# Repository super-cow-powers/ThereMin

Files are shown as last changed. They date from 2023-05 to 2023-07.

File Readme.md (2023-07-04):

# ThereMin()
Minimal Digital Theremin, based on a pair of NE555p timers and an STM32G0.

Completed Device

## Theory of Operation
The device uses a pair of 555 timers to translate hand-position to frequency, which is measured by the STM32 and then used to modify a generated sine wave.

The 555 timers operate in the usual astable mode except with the capacitor replaced with an "antenna"; this forms a capacitor between you and the metal whose value varies with the gap between you and the antenna, which then varies the frequency of the 555 output.

The STM32 measures the period of the 555's output wave, calculating the offset from the initial state (calibration is done at power-on); the offset from the calibrated value is used to calculate an amplitude coefficient and a pitch offset. The amplitude coefficient divides a full-scale sine wave which is stored in a lookup table. The pitch offset is used to increase or decrease the time between changes of output value (by adjusting a timer's reload-point), thus stretching or compacting the output wave as required - although with an apparently exponential response, which is partially corrected by the firmware.

The signal is fed into a TDA2822 amplifier in single-ended mode (SE gave better stability on veroboard) with the input amplitude controlled by a potentiometer; the amplifier feeds into either an (optional) internal speaker or headphone jack depending on a SPDT switch.

## Hardware
The hardware is designed in KiCad. If you want to build your own, you're free to use the files so long as you don't try and blame me for anything which goes wrong as a result; it'd be nice to keep my name on the board, too.

The devices are fairly cheap - about £12-15 for the basic device with no LEDs or pitch-adjust potentiometer (which haven't been written in) - I used JLC for the boards and sourced most of the parts from DigiKey.

The cases are drilled by hand, using a 13mm bit for the rear cables, a 6.5mm and 7.5mm bit for the front switch and pot, and a 6mm bit for the (four) holes on the top. There's no drilling template, just use a centre-punch in the right place for the hole's purpose and drill. 

### "Antennae"
The Antennae (capacitor plates, really) are not too critical. Mine are made from thin brass rod which will fit into the jacks; any conductor which fits the jacks will work - make it into a loop which looks like a theremin antenna aught, with one "leg" slightly shorter than the other for the non-connected end. The bigger the antenna the more sensitive the response generally speaking, although I've found that there's not much to gain with this device from a huge antenna.

## Firmware
The firmware uses device files from ST Micro and ARM CMSIS, the rest can be blamed on me. The ST HAL is not being used, because it looked like a good idea to not use it when I started...

The software is fairly simple although does make heavy use of the DMA engine and Timers - these are described in the chip reference manual and, briefly, in comments.

### Building
The firmware builds with Make and Arm GCC (I suspect ARMCC6 would work, too, but I'm not going to try it) and should build on most *nix systems - it might work on Windows under WSL or mingw, but you're on your own with that one. For anyone who doesn't want to build the firmware, the latest binary is just in the build directory.

The firmware can be flashed with your favourite flashing tool; a script for an ST-Link V2 with OpenOCD is provided, but I recommend just using STMCubeProg if you're either inexperienced or running Windows. 

-----

This was initially designed as a lab kit for the [York Engineering Society](https://github.com/EngYork).

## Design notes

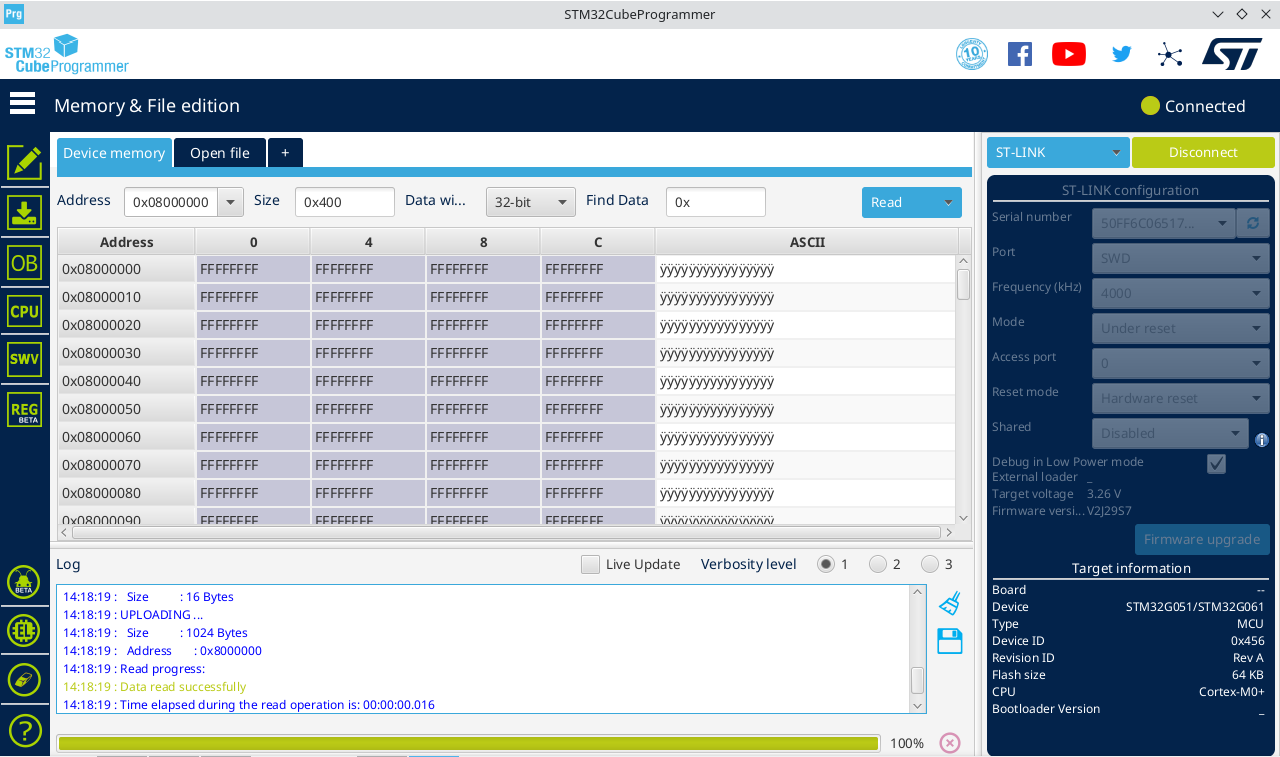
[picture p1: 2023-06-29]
cube prog.png

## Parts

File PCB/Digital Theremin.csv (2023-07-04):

Source: | /home/david/ThereMin/PCB/Digital Theremin.kicad_sch
Date: | Tue 04 Jul 2023 15:31:06 BST
Tool: | Eeschema 6.0.11-3.fc37
Generator: | /usr/share/kicad/plugins/bom_csv_grouped_by_value.py
Component Count: | 59
Individual Components:
Item | Qty | Reference(s) | Value | LibPart | Footprint | Datasheet | PN
 |  | ANT1 | Antenna | Device:Antenna | MountingHole:MountingHole_3.2mm_M3_Pad_Via | ~ | PRT-09739
 |  | ANT2 | Antenna | Device:Antenna | MountingHole:MountingHole_3.2mm_M3_Pad_Via | ~ | PRT-09739
 |  | C1 | .1u | Device:C | Capacitor_THT:C_Rect_L4.0mm_W2.5mm_P2.50mm | ~
 |  | C2 | .1u | Device:C | Capacitor_THT:C_Rect_L4.0mm_W2.5mm_P2.50mm | ~
 |  | C3 | .1u | Device:C | Capacitor_THT:C_Rect_L4.0mm_W2.5mm_P2.50mm | ~
 |  | C4 | 1u | Device:C | Capacitor_THT:C_Rect_L4.0mm_W2.5mm_P2.50mm | ~
 |  | C5 | .1u | Device:C | Capacitor_THT:C_Rect_L4.0mm_W2.5mm_P2.50mm | ~
 |  | C6 | 100u | Device:C_Polarized | Capacitor_THT:CP_Radial_D5.0mm_P2.50mm | ~ | ESK107M016AC3AA
 |  | C7 | 100u | Device:C_Polarized | Capacitor_THT:CP_Radial_D5.0mm_P2.50mm | ~ | ESK107M016AC3AA
 |  | C8 | 470u | Device:C_Polarized | Capacitor_THT:CP_Radial_D5.0mm_P2.50mm | ~ | 860010273011
 |  | C9 | .1u | Device:C | Capacitor_THT:C_Rect_L4.0mm_W2.5mm_P2.50mm | ~
 |  | C10 | .1u | Device:C | Capacitor_THT:C_Rect_L4.0mm_W2.5mm_P2.50mm | ~
 |  | C12 | .1u | Device:C | Capacitor_THT:C_Rect_L4.0mm_W2.5mm_P2.50mm | ~
 |  | C13 | .1u | Device:C | Capacitor_THT:C_Rect_L4.0mm_W2.5mm_P2.50mm | ~
 |  | C14 | .1u | Device:C | Capacitor_THT:C_Rect_L4.0mm_W2.5mm_P2.50mm | ~
 |  | C15 | .1u | Device:C | Capacitor_THT:C_Rect_L4.0mm_W2.5mm_P2.50mm | ~
 |  | C16 | DNF | Device:C | Capacitor_THT:C_Rect_L4.0mm_W2.5mm_P2.50mm | ~
 |  | D1 | DNF | Device:LED | LED_THT:LED_D5.0mm | ~
 |  | D2 | DNF | Device:LED | LED_THT:LED_D5.0mm | ~
 |  | D3 | DNF | Device:LED | LED_THT:LED_D5.0mm | ~
 |  | D4 | D_Zener 12V | Device:D_Zener | Diode_THT:D_DO-41_SOD81_P10.16mm_Horizontal | ~
 |  | D5 | D | Device:D_Schottky | Diode_THT:D_DO-41_SOD81_P10.16mm_Horizontal | ~
 |  | D6 | D | Device:D_Schottky | Diode_THT:D_DO-41_SOD81_P10.16mm_Horizontal | ~
 |  | H1 | MountingHole_Pad | Mechanical:MountingHole_Pad | MountingHole:MountingHole_3.7mm_Pad | ~
 |  | H2 | MountingHole_Pad | Mechanical:MountingHole_Pad | MountingHole:MountingHole_3.7mm_Pad | ~
 |  | J1 | Conn_01x02_Female | Connector:Conn_01x02_Female | Connector_PinHeader_2.54mm:PinHeader_1x02_P2.54mm_Vertical | ~
 |  | J2 | AudioJack3_Dual_Switch | Connector:AudioJack3_Dual_Switch | Connector_Audio:Jack_3.5mm_CUI_SJ1-3525N_Horizontal | ~ | SJ1-3525NG-PI
 |  | J3 | USB_B_Micro | Connector:USB_B_Micro | Connector_USB:USB_Micro-B_Amphenol_10104110_Horizontal | ~
 |  | J4 | Conn_01x03_Female | Connector:Conn_01x03_Female | Connector_PinHeader_2.54mm:PinHeader_1x03_P2.54mm_Vertical | ~
 |  | JP1 | Jumper_2_Open | Jumper:Jumper_2_Open | Jumper:SolderJumper-2_P1.3mm_Open_TrianglePad1.0x1.5mm | ~
 |  | JP2 | Jumper_2_Open | Jumper:Jumper_2_Open | Jumper:SolderJumper-2_P1.3mm_Open_TrianglePad1.0x1.5mm | ~
 |  | R1 | DNF | Device:R | Resistor_THT:R_Axial_DIN0207_L6.3mm_D2.5mm_P10.16mm_Horizontal | ~
 |  | R2 | DNF | Device:R | Resistor_THT:R_Axial_DIN0207_L6.3mm_D2.5mm_P10.16mm_Horizontal | ~
 |  | R3 | DNF | Device:R | Resistor_THT:R_Axial_DIN0207_L6.3mm_D2.5mm_P10.16mm_Horizontal | ~
 |  | R4 | DNF | Device:R | Resistor_THT:R_Axial_DIN0207_L6.3mm_D2.5mm_P10.16mm_Horizontal | ~
 |  | R5 | 510k | Device:R | Resistor_THT:R_Axial_DIN0207_L6.3mm_D2.5mm_P10.16mm_Horizontal | ~
 |  | R7 | 4.7 | Device:R | Resistor_THT:R_Axial_DIN0207_L6.3mm_D2.5mm_P10.16mm_Horizontal | ~
 |  | R10 | 1K | Device:R | Resistor_THT:R_Axial_DIN0207_L6.3mm_D2.5mm_P10.16mm_Horizontal | ~
 |  | R11 | 1K | Device:R | Resistor_THT:R_Axial_DIN0207_L6.3mm_D2.5mm_P10.16mm_Horizontal | ~
 |  | R12 | 1Meg | Device:R | Resistor_THT:R_Axial_DIN0207_L6.3mm_D2.5mm_P10.16mm_Horizontal | ~
 |  | R13 | 1Meg | Device:R | Resistor_THT:R_Axial_DIN0207_L6.3mm_D2.5mm_P10.16mm_Horizontal | ~
 |  | R14 | 1Meg | Device:R | Resistor_THT:R_Axial_DIN0207_L6.3mm_D2.5mm_P10.16mm_Horizontal | ~
 |  | R15 | 1Meg | Device:R | Resistor_THT:R_Axial_DIN0207_L6.3mm_D2.5mm_P10.16mm_Horizontal | ~
 |  | R16 | 10k | Device:R | Resistor_THT:R_Axial_DIN0207_L6.3mm_D2.5mm_P10.16mm_Horizontal | ~
 |  | R17 | 10k | Device:R | Resistor_THT:R_Axial_DIN0207_L6.3mm_D2.5mm_P10.16mm_Horizontal | ~
 |  | RV1 | DNF | Device:R_Potentiometer | Connector_PinHeader_2.54mm:PinHeader_1x03_P2.54mm_Vertical | ~
 |  | RV2 | 10k | Device:R_Potentiometer | Connector_PinHeader_2.54mm:PinHeader_1x03_P2.54mm_Vertical | ~
 |  | SP1 | Speaker | Device:Speaker | Connector_PinHeader_2.54mm:PinHeader_1x02_P2.54mm_Vertical | ~
 |  | SW1 | DNF | Switch:SW_Push | Button_Switch_THT:SW_PUSH_6mm | ~
 |  | SW2 | DNF | Switch:SW_Push | Button_Switch_THT:SW_PUSH_6mm | ~
 |  | SW3 | SW_SPDT | Switch:SW_SPDT | Connector_PinHeader_2.54mm:PinHeader_1x03_P2.54mm_Vertical | ~
 |  | SWD1 | Conn_ARM_JTAG_SWD_10 | Connector:Conn_ARM_JTAG_SWD_10 | Connector_PinHeader_1.27mm:PinHeader_2x05_P1.27mm_Vertical | http://infocenter.arm.com/help/topic/com.arm.doc.ddi0314h/DDI0314H_coresight_components_trm.pdf | 20021111-00010T1LF
 |  | TP1 | TestPoint | Connector:TestPoint | TestPoint:TestPoint_Loop_D2.50mm_Drill1.0mm | ~
 |  | TP2 | TestPoint | Connector:TestPoint | TestPoint:TestPoint_Loop_D2.50mm_Drill1.0mm | ~
 |  | U1 | AP2204K-3.0 | Regulator_Linear:AP2204K-3.0 | Package_TO_SOT_SMD:SOT-23-5 | https://www.diodes.com/assets/Datasheets/AP2204.pdf
 |  | U2 | TDA2822 | project_lib:TDA2822 | Package_SO:SOIC-8_3.9x4.9mm_P1.27mm
 |  | U3 | NE555P | Timer:NE555P | Package_DIP:DIP-8_W7.62mm | http://www.ti.com/lit/ds/symlink/ne555.pdf
 |  | U4 | NE555P | Timer:NE555P | Package_DIP:DIP-8_W7.62mm | http://www.ti.com/lit/ds/symlink/ne555.pdf
 |  | U5 | STM32G051K8T6 | MCU_ST_STM32G0:STM32G071KxT | Package_QFP:LQFP-32_7x7mm_P0.8mm | https://www.st.com/resource/en/datasheet/stm32g071kb.pdf
Collated Components:
Item | Qty | Reference(s) | Value | LibPart | Footprint | Datasheet | PN
1 | 2 | ANT1, ANT2 | Antenna | Device:Antenna | MountingHole:MountingHole_3.2mm_M3_Pad_Via | ~ | PRT-09739
2 | 10 | C1, C2, C3, C5, C9, C10, C12, C13, C14, C15 | .1u | Device:C | Capacitor_THT:C_Rect_L4.0mm_W2.5mm_P2.50mm | ~
3 | 1 | C4 | 1u | Device:C | Capacitor_THT:C_Rect_L4.0mm_W2.5mm_P2.50mm | ~
4 | 2 | C6, C7 | 100u | Device:C_Polarized | Capacitor_THT:CP_Radial_D5.0mm_P2.50mm | ~ | ESK107M016AC3AA
5 | 1 | C8 | 470u | Device:C_Polarized | Capacitor_THT:CP_Radial_D5.0mm_P2.50mm | ~ | 860010273011
6 | 1 | C16 | DNF | Device:C | Capacitor_THT:C_Rect_L4.0mm_W2.5mm_P2.50mm | ~
7 | 3 | D1, D2, D3 | DNF | Device:LED | LED_THT:LED_D5.0mm | ~
8 | 1 | D4 | D_Zener 12V | Device:D_Zener | Diode_THT:D_DO-41_SOD81_P10.16mm_Horizontal | ~
9 | 2 | D5, D6 | D | Device:D_Schottky | Diode_THT:D_DO-41_SOD81_P10.16mm_Horizontal | ~
10 | 2 | H1, H2 | MountingHole_Pad | Mechanical:MountingHole_Pad | MountingHole:MountingHole_3.7mm_Pad | ~
11 | 1 | J1 | Conn_01x02_Female | Connector:Conn_01x02_Female | Connector_PinHeader_2.54mm:PinHeader_1x02_P2.54mm_Vertical | ~
12 | 1 | J2 | AudioJack3_Dual_Switch | Connector:AudioJack3_Dual_Switch | Connector_Audio:Jack_3.5mm_CUI_SJ1-3525N_Horizontal | ~ | SJ1-3525NG-PI
13 | 1 | J3 | USB_B_Micro | Connector:USB_B_Micro | Connector_USB:USB_Micro-B_Amphenol_10104110_Horizontal | ~
14 | 1 | J4 | Conn_01x03_Female | Connector:Conn_01x03_Female | Connector_PinHeader_2.54mm:PinHeader_1x03_P2.54mm_Vertical | ~
15 | 2 | JP1, JP2 | Jumper_2_Open | Jumper:Jumper_2_Open | Jumper:SolderJumper-2_P1.3mm_Open_TrianglePad1.0x1.5mm | ~
16 | 4 | R1, R2, R3, R4 | DNF | Device:R | Resistor_THT:R_Axial_DIN0207_L6.3mm_D2.5mm_P10.16mm_Horizontal | ~
17 | 1 | R5 | 510k | Device:R | Resistor_THT:R_Axial_DIN0207_L6.3mm_D2.5mm_P10.16mm_Horizontal | ~
18 | 1 | R7 | 4.7 | Device:R | Resistor_THT:R_Axial_DIN0207_L6.3mm_D2.5mm_P10.16mm_Horizontal | ~
19 | 2 | R10, R11 | 1K | Device:R | Resistor_THT:R_Axial_DIN0207_L6.3mm_D2.5mm_P10.16mm_Horizontal | ~
20 | 4 | R12, R13, R14, R15 | 1Meg | Device:R | Resistor_THT:R_Axial_DIN0207_L6.3mm_D2.5mm_P10.16mm_Horizontal | ~
21 | 2 | R16, R17 | 10k | Device:R | Resistor_THT:R_Axial_DIN0207_L6.3mm_D2.5mm_P10.16mm_Horizontal | ~
22 | 1 | RV1 | DNF | Device:R_Potentiometer | Connector_PinHeader_2.54mm:PinHeader_1x03_P2.54mm_Vertical | ~
23 | 1 | RV2 | 10k | Device:R_Potentiometer | Connector_PinHeader_2.54mm:PinHeader_1x03_P2.54mm_Vertical | ~
24 | 1 | SP1 | Speaker | Device:Speaker | Connector_PinHeader_2.54mm:PinHeader_1x02_P2.54mm_Vertical | ~
25 | 2 | SW1, SW2 | DNF | Switch:SW_Push | Button_Switch_THT:SW_PUSH_6mm | ~
26 | 1 | SW3 | SW_SPDT | Switch:SW_SPDT | Connector_PinHeader_2.54mm:PinHeader_1x03_P2.54mm_Vertical | ~
27 | 1 | SWD1 | Conn_ARM_JTAG_SWD_10 | Connector:Conn_ARM_JTAG_SWD_10 | Connector_PinHeader_1.27mm:PinHeader_2x05_P1.27mm_Vertical | http://infocenter.arm.com/help/topic/com.arm.doc.ddi0314h/DDI0314H_coresight_components_trm.pdf | 20021111-00010T1LF
28 | 2 | TP1, TP2 | TestPoint | Connector:TestPoint | TestPoint:TestPoint_Loop_D2.50mm_Drill1.0mm | ~
29 | 1 | U1 | AP2204K-3.0 | Regulator_Linear:AP2204K-3.0 | Package_TO_SOT_SMD:SOT-23-5 | https://www.diodes.com/assets/Datasheets/AP2204.pdf
30 | 1 | U2 | TDA2822 | project_lib:TDA2822 | Package_SO:SOIC-8_3.9x4.9mm_P1.27mm
31 | 2 | U3, U4 | NE555P | Timer:NE555P | Package_DIP:DIP-8_W7.62mm | http://www.ti.com/lit/ds/symlink/ne555.pdf
32 | 1 | U5 | STM32G051K8T6 | MCU_ST_STM32G0:STM32G071KxT | Package_QFP:LQFP-32_7x7mm_P0.8mm | https://www.st.com/resource/en/datasheet/stm32g071kb.pdf

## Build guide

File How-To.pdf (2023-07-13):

Building Your Theremin.

## Parts

To build your Theremin, you will need the following parts:

- 10 * 0.1uF capacitors (C1, C2, C3, C5, C9, C10, C12, C13, C14, C15)
- 1 * 1uF capacitor (C4)
- 2 * 100uF capacitors (C6, C7)
- 1 * 470uF capacitor (C8)
- 2 * DO-41 size Schottky diodes (D5, D6)
- 1 * CUI SJ1-3525N 3.5mm audio jack (J2)
- 1 * Amphenol 10104110 USB port (J3)
- 1 * 510k resistor (R5)
- 1 * 4.7r resistor (R7)
- 2 * 1k resistors (R10, R11)
- 4 * 1M resistors (R12, R13, R14, R15)
- 2 * 10k resistors (R16, R17)
- 1 * 0.05” 10-pin debug header (SWD1)
- 1 * AP2204K-3.0 (pre-fitted) (U1)
- 1 * TDA2822 (pre-fitted) (U2)
- 2 * NE555P (U3, U4)
- 1 * STM32G051K8T6 (U5)
- 1 * 10k potentiometer (RV2)
- 1 * SPDT switch (SW3)
- 2 * SparkFun PRT-09739 binding posts (ANT1, ANT2)
- 1 * Hammond 1591XXSTBU, 1591XXSSBK, or 1591XXSSFLBK case.
- Antenna rods

## Surface Mount Parts

If your board is partially assembled, the only Surface Mount part is the STM32 microcontroller, U5. This should be fitted first as it can be fiddly and is not made easier by having other parts in the way.

First apply plenty of Flux to the U5 pad, then, using tweezers, grab the chip by the sides (just above the legs) and place it in position with the dot on the chip at the same corner as the line on the board (see below).

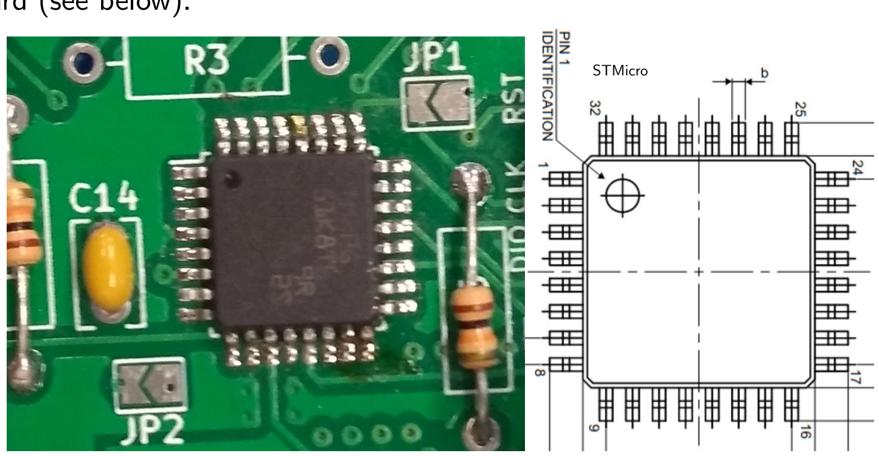
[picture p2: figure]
STMicro

Once in place, you can drag solder the chip. First solder a corner pin and then solder a pin at the opposite corner; then add solder to your iron’s tip and drag along each row of pins in turn – you may have to add more flux for each row.

For a detailed explanation, watch this video: https://youtu.be/hoLf8gvvXXU?t=363

Once you have soldered all four rows, check for solder
between any of the pins. These “bridges” can, if small,

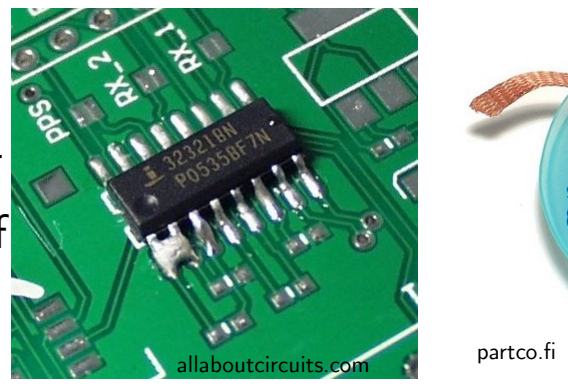
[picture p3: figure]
allaboutcircuits.com; partco.fi

be removed with flux and a clean tip; if they are larger
then apply flux, lay a short bit of solder wick on top of the bridged pins, and press the tip onto the wick
dragging along the area (make sure to remove the
wick whilst the iron is still in place!).

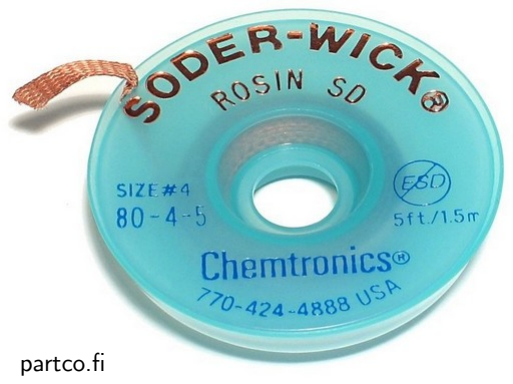
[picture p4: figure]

A hot-air gun can also work on small bridges, with the solder flowing into the pads.

The other Surface Mount parts (TDA2822, AP2204K-3.0, USB Port) can now be fitted, if they are not already. They are soldered in a similar way to the STM32, but are easier as they have a larger pin pitch.

## Through Hole Parts

The THT parts can now be attached. Start with the resistors and diodes, then attach the debug header and audio jack, then attach the two NE555 chips, then the capacitors.

An optional speaker may be connected, if available, to SP1.

### Special Instructions

The switch, potentiometer, and binding posts require special care and attention.

### Binding Posts

The binding posts should have the top plastic unscrewed and removed as well as all the nuts and washers removed (if attached); they should then be soldered in position on the top of the board using plenty of solder and with Blu Tack to keep them straight, once attached the threaded part sticking through the bottom of the board should be snipped off to allow the board to mount in the case.

### Switch and Potentiometer

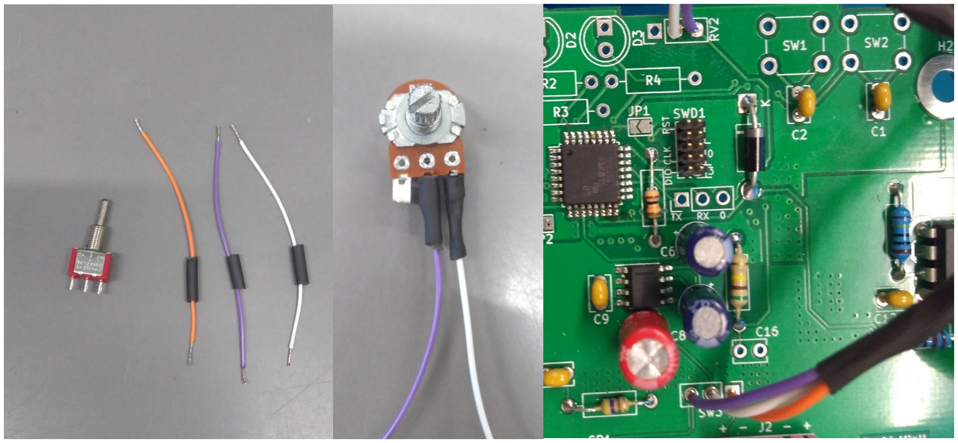
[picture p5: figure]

The switch and potentiometer attach with wires. For the switch cut three equal-length wires and for the potentiometer cut two - stripping, twisting, and adding solder to the ends of each wire.

Attach the three wires to the three switch pins and connect the wires to the board (SW3) in the same order as on the switch.

Attach the two wires to the inner and one outer pin of the potentiometer, connecting these between the two circular pads of the RV2.

## Case

The case can now be prepared. It is required to drill two holes in the front, two in the back, and four in the top.

The front needs a 6.5mm hole for the switch and a 7.5mm hole for the potentiometer.

The back needs two 13mm holes for the USB port and the audio jack.

The top needs two 6mm (or 6.5mm if you prefer) holes at each end with one hole per pair exactly above the hole in the binding post when the board is mounted in the case and with the other hole positioned to allow the second leg of each antenna to enter the case and prevent the antenna moving around.

All the holes should be marked out first using a centre-punch and engineer’s square.

## Antennae

The “antennae” can be made from any conductive rod which will fit into the binding posts and is easy to work, and should be made to a scale correct for the size of the case.

For the left side, you need a wide antenna which is roughly parallel to the desk; for the right side a long, thin, roughly vertical antenna is required. Make both of these with two legs.

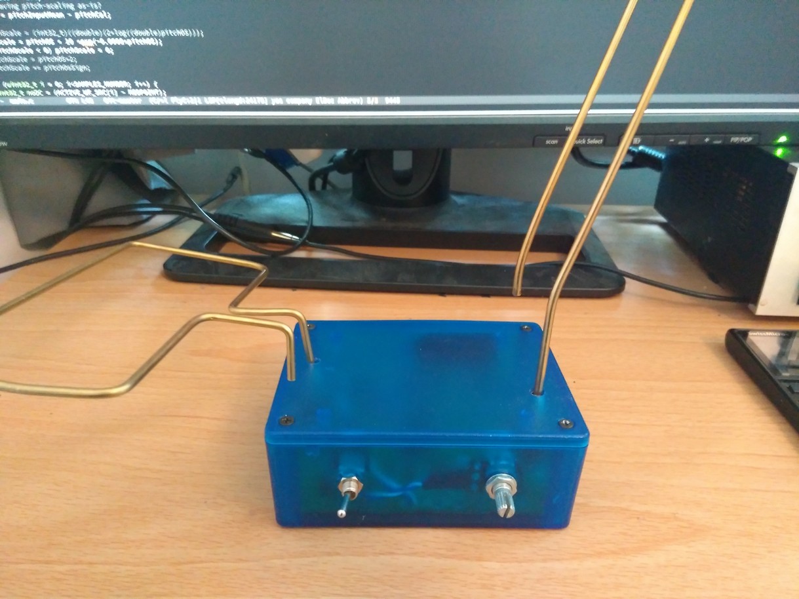
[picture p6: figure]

## Programming

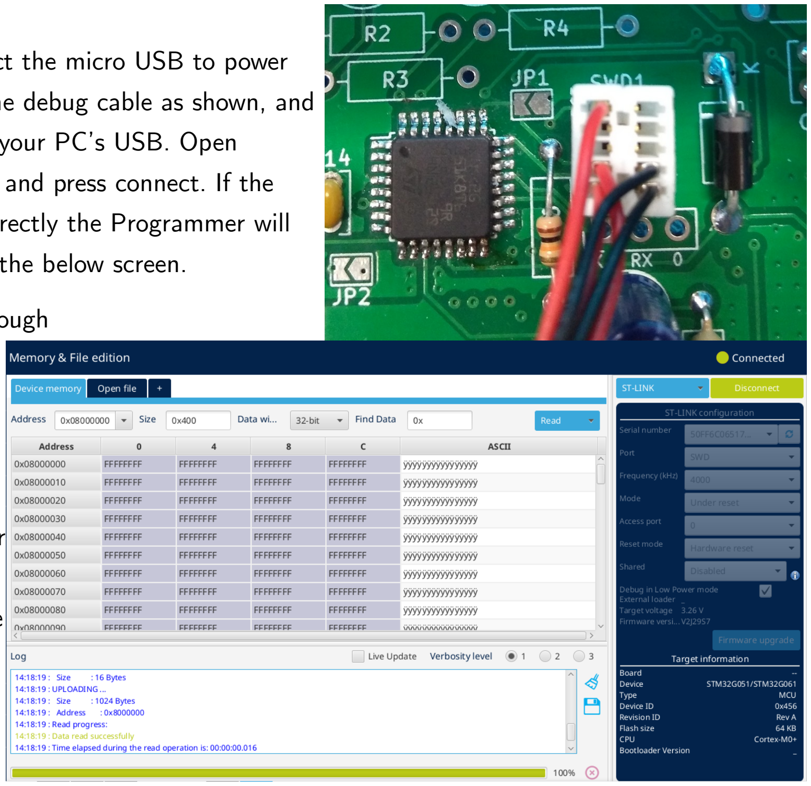
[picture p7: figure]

To test the device connect the micro USB to power the Theremin, connect the debug cable as shown, and connect the debugger to your PC’s USB. Open STM32CubeProgrammer and press connect. If the board is built roughly correctly the Programmer will connect and you will see the below screen.

Flash the programme through STM32CubeProgrammer
– Open File and write,
then disconnect.

If the board is correct, a sound will be heard either on the audio jack or
speaker depending on the
switch position; the
sound should change
when the binding posts
are touched.

If no output is seen, check your board for bad connections.

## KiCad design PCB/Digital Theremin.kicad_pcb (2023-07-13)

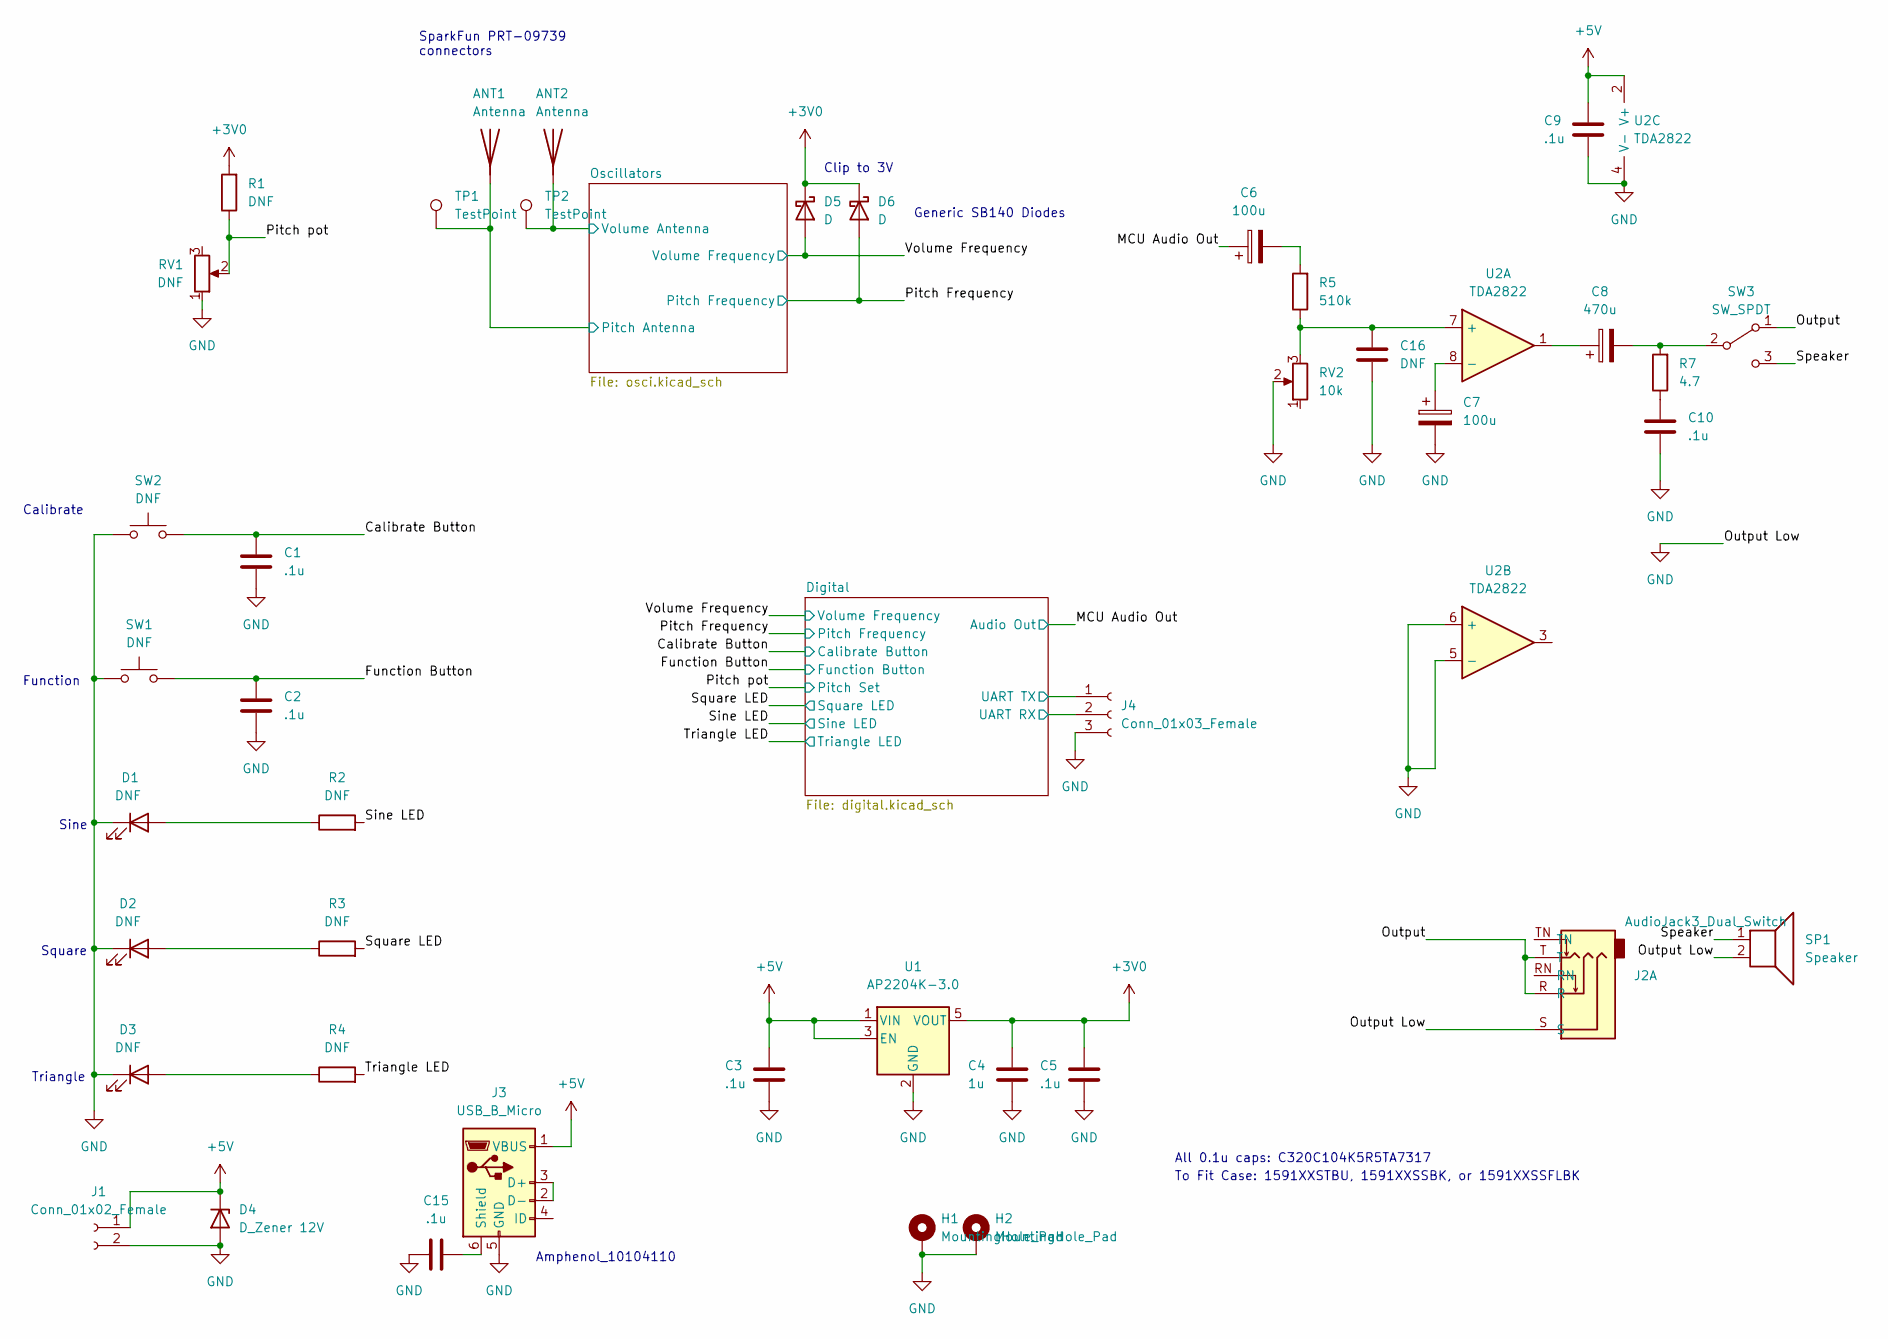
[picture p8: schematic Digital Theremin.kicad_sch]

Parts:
ANT1, ANT2: Antenna; MountingHole_3.2mm_M3_Pad_Via
C1, C2, C3, C5, C9, C10, C15: .1u; C_Rect_L4.0mm_W2.5mm_P2.50mm
C4: 1u; C_Rect_L4.0mm_W2.5mm_P2.50mm
C6, C7: 100u; CP_Radial_D5.0mm_P2.50mm
C8: 470u; CP_Radial_D5.0mm_P2.50mm
C16: DNF; C_Rect_L4.0mm_W2.5mm_P2.50mm
D1, D2, D3: DNF; LED_D5.0mm
D4: D_Zener 12V; D_DO-41_SOD81_P10.16mm_Horizontal
D5, D6: D; D_DO-41_SOD81_P10.16mm_Horizontal
H1, H2: MountingHole_Pad; MountingHole_3.7mm_Pad
J1: Conn_01x02_Female; PinHeader_1x02_P2.54mm_Vertical
J2: AudioJack3_Dual_Switch; Jack_3.5mm_CUI_SJ1-3525N_Horizontal
J3: USB_B_Micro; USB_Micro-B_Amphenol_10104110_Horizontal
J4: Conn_01x03_Female; PinHeader_1x03_P2.54mm_Vertical
R1, R2, R3, R4: DNF; R_Axial_DIN0207_L6.3mm_D2.5mm_P10.16mm_Horizontal
R5: 510k; R_Axial_DIN0207_L6.3mm_D2.5mm_P10.16mm_Horizontal
R7: 4.7; R_Axial_DIN0207_L6.3mm_D2.5mm_P10.16mm_Horizontal
RV1: DNF; PinHeader_1x03_P2.54mm_Vertical
RV2: 10k; PinHeader_1x03_P2.54mm_Vertical
SP1: Speaker; PinHeader_1x02_P2.54mm_Vertical
SW1, SW2: DNF; SW_PUSH_6mm
SW3: SW_SPDT; PinHeader_1x03_P2.54mm_Vertical
TP1, TP2: TestPoint; TestPoint_Loop_D2.50mm_Drill1.0mm
U1: AP2204K-3.0; SOT-23-5
U2: TDA2822; SOIC-8_3.9x4.9mm_P1.27mm

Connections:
+3V0: C4.1, C5.1, D5.1 (K), D6.1 (K), R1.2, U1.5 (VOUT); also elsewhere on the board
+5V: C3.1, C9.1, D4.1 (K), J1.1, J3.1 (VBUS), U1.1 (VIN), U1.3 (EN), U2.2 (V+); also elsewhere on the board
/Calibrate Button: C1.2, SW2.2; also elsewhere on the board
/Digital/UART RX: J4.2; also elsewhere on the board
/Digital/UART TX: J4.1; also elsewhere on the board
/Function Button: C2.2, SW1.2; also elsewhere on the board
/MCU Audio Out: C6.1; also elsewhere on the board
/Oscillators/Pitch Antenna: ANT1.1 (A), TP1.1; also elsewhere on the board
/Oscillators/Volume Antenna: ANT2.1 (A), TP2.1; also elsewhere on the board
/Output: J2.R, J2.T, SW3.1 (A)
/Pitch Frequency: D6.2 (A); also elsewhere on the board
/Pitch pot: R1.1, RV1.2; also elsewhere on the board
/Sine LED: R2.2; also elsewhere on the board
/Speaker: SP1.1, SW3.3 (C)
/Square LED: R3.2; also elsewhere on the board
/Triangle LED: R4.2; also elsewhere on the board
/Volume Frequency: D5.2 (A); also elsewhere on the board
GND: C1.1, C2.1, C3.2, C4.2, C5.2, C7.2, C9.2, C10.1, C15.2, C16.1, D1.1 (K), D2.1 (K), D3.1 (K), D4.2 (A), H1.1, H2.1, J1.2, J2.S, J3.5 (GND), J4.3, RV1.1, RV2.2, SP1.2, SW1.1, SW2.1, U1.2 (GND), U2.4 (V-), U2.5 (-), U2.6 (+); also elsewhere on the board
unnamed: C6.2, R5.2
unnamed: C7.1, U2.8 (-)
unnamed: C8.1, U2.1
unnamed: C8.2, R7.2, SW3.2 (B)
unnamed: C10.2, R7.1
unnamed: C15.1, J3.6 (Shield)
unnamed: C16.2, R5.1, RV2.3, U2.7 (+)
unnamed: D1.2 (A), R2.1
unnamed: D2.2 (A), R3.1
unnamed: D3.2 (A), R4.1
unnamed: J3.2 (D-), J3.3 (D+)

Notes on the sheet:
Generic SB140 Diodes
Square
Triangle
All 0.1u caps: C320C104K5R5TA7317
To Fit Case: 1591XXSTBU, 1591XXSSBK, or 1591XXSSFLBK
Clip to 3V
SparkFun PRT-09739 connectors
Sine
Calibrate
Function
Amphenol_10104110

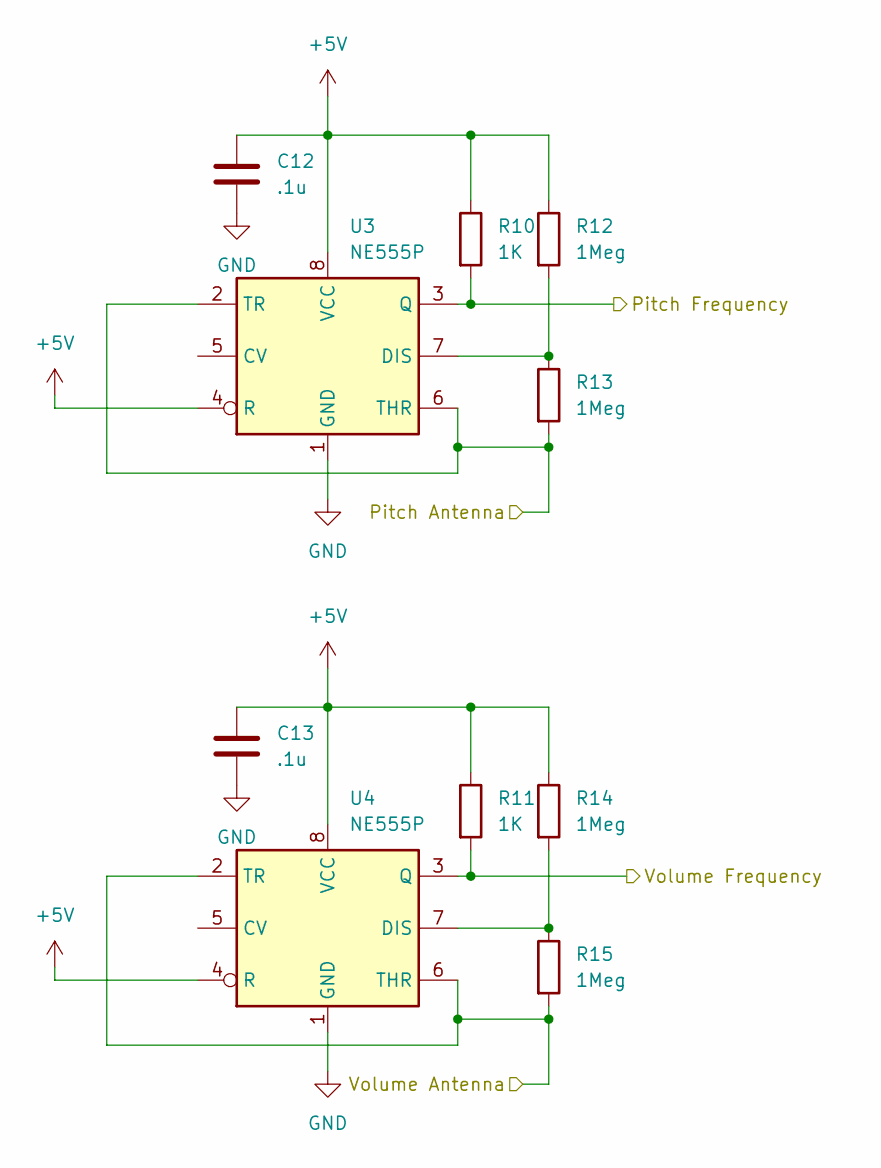
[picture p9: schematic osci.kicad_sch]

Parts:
C12, C13: .1u; C_Rect_L4.0mm_W2.5mm_P2.50mm
R10, R11: 1K; R_Axial_DIN0207_L6.3mm_D2.5mm_P10.16mm_Horizontal
R12, R13, R14, R15: 1Meg; R_Axial_DIN0207_L6.3mm_D2.5mm_P10.16mm_Horizontal
U3, U4: NE555P; DIP-8_W7.62mm

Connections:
+5V: C12.1, C13.1, R10.1, R11.1, R12.1, R14.1, U3.4 (R), U3.8 (VCC), U4.4 (R), U4.8 (VCC); also elsewhere on the board
/Oscillators/Pitch Antenna: R13.2, U3.2 (TR), U3.6 (THR); also elsewhere on the board
/Oscillators/Volume Antenna: R15.2, U4.2 (TR), U4.6 (THR); also elsewhere on the board
/Pitch Frequency: R10.2, U3.3 (Q); also elsewhere on the board
/Volume Frequency: R11.2, U4.3 (Q); also elsewhere on the board
GND: C12.2, C13.2, U3.1 (GND), U4.1 (GND); also elsewhere on the board
unnamed: R12.2, R13.1, U3.7 (DIS)
unnamed: R14.2, R15.1, U4.7 (DIS)

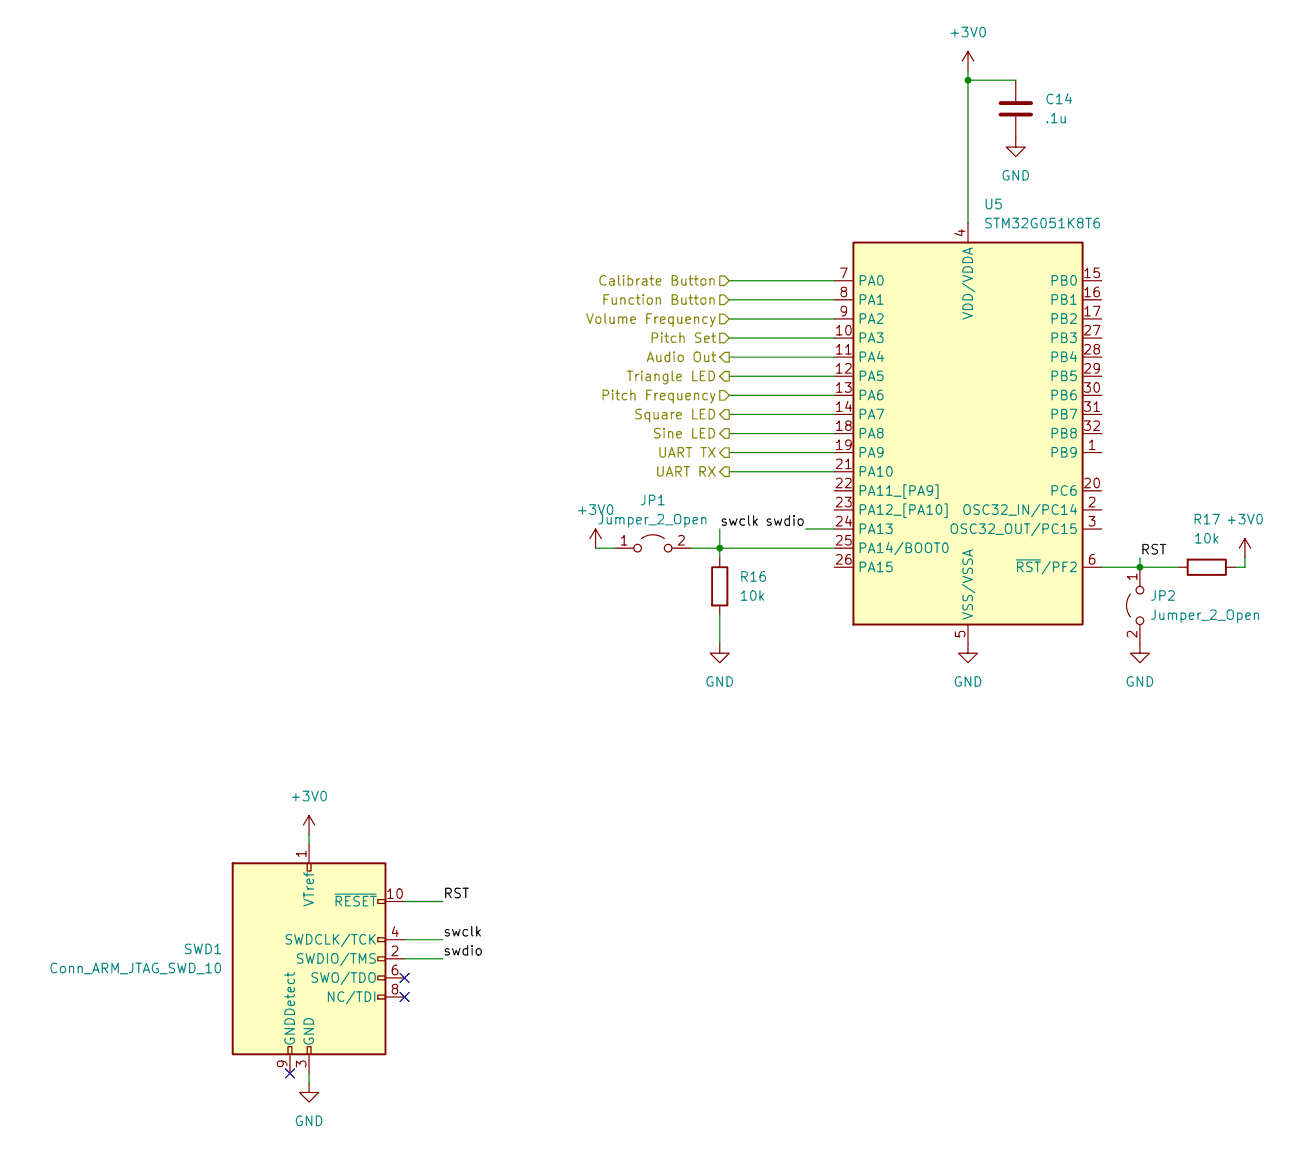
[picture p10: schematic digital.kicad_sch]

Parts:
C14: .1u; C_Rect_L4.0mm_W2.5mm_P2.50mm
JP1, JP2: Jumper_2_Open; SolderJumper-2_P1.3mm_Open_TrianglePad1.0x1.5mm
R16, R17: 10k; R_Axial_DIN0207_L6.3mm_D2.5mm_P10.16mm_Horizontal
SWD1: Conn_ARM_JTAG_SWD_10; PinHeader_2x05_P1.27mm_Vertical
U5: STM32G051K8T6; LQFP-32_7x7mm_P0.8mm

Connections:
+3V0: C14.2, JP1.1 (A), R17.1, SWD1.1 (VTref), U5.4 (VDD/VDDA); also elsewhere on the board
/Calibrate Button: U5.7 (PA0); also elsewhere on the board
/Digital/RST: JP2.1 (A), R17.2, SWD1.10 (~RESET), U5.6 (~RST/PF2)
/Digital/UART RX: U5.21 (PA10); also elsewhere on the board
/Digital/UART TX: U5.19 (PA9); also elsewhere on the board
/Digital/swclk: JP1.2 (B), R16.1, SWD1.4 (SWDCLK/TCK), U5.25 (PA14/BOOT0)
/Digital/swdio: SWD1.2 (SWDIO/TMS), U5.24 (PA13)
/Function Button: U5.8 (PA1); also elsewhere on the board
/MCU Audio Out: U5.11 (PA4); also elsewhere on the board
/Pitch Frequency: U5.13 (PA6); also elsewhere on the board
/Pitch pot: U5.10 (PA3); also elsewhere on the board
/Sine LED: U5.18 (PA8); also elsewhere on the board
/Square LED: U5.14 (PA7); also elsewhere on the board
/Triangle LED: U5.12 (PA5); also elsewhere on the board
/Volume Frequency: U5.9 (PA2); also elsewhere on the board
GND: C14.1, JP2.2 (B), R16.2, SWD1.3 (GND), SWD1.5 (GND), U5.5 (VSS/VSSA); also elsewhere on the board

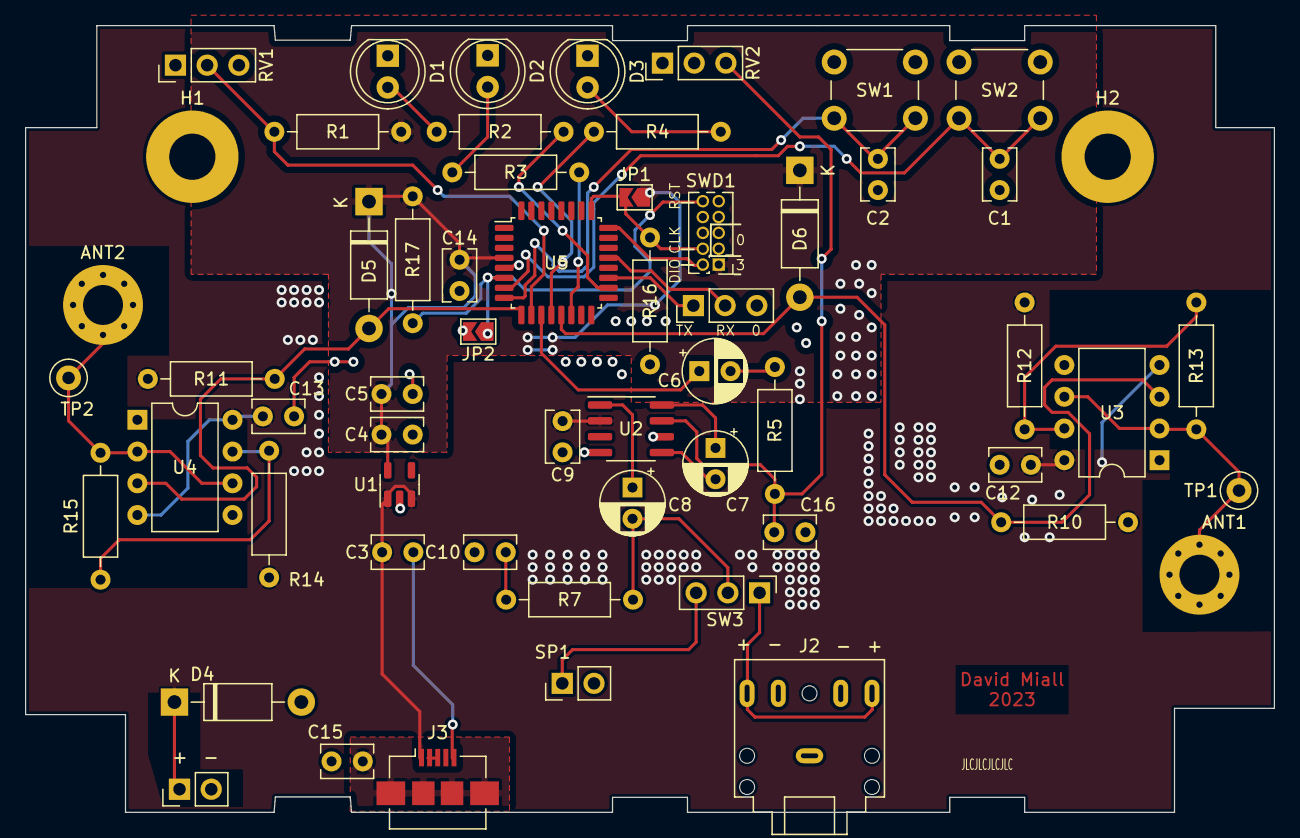
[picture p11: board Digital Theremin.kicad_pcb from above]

Board: 2 copper layers, 100.0 x 63.0 mm, 59 parts (0 on the bottom side), 34 nets.

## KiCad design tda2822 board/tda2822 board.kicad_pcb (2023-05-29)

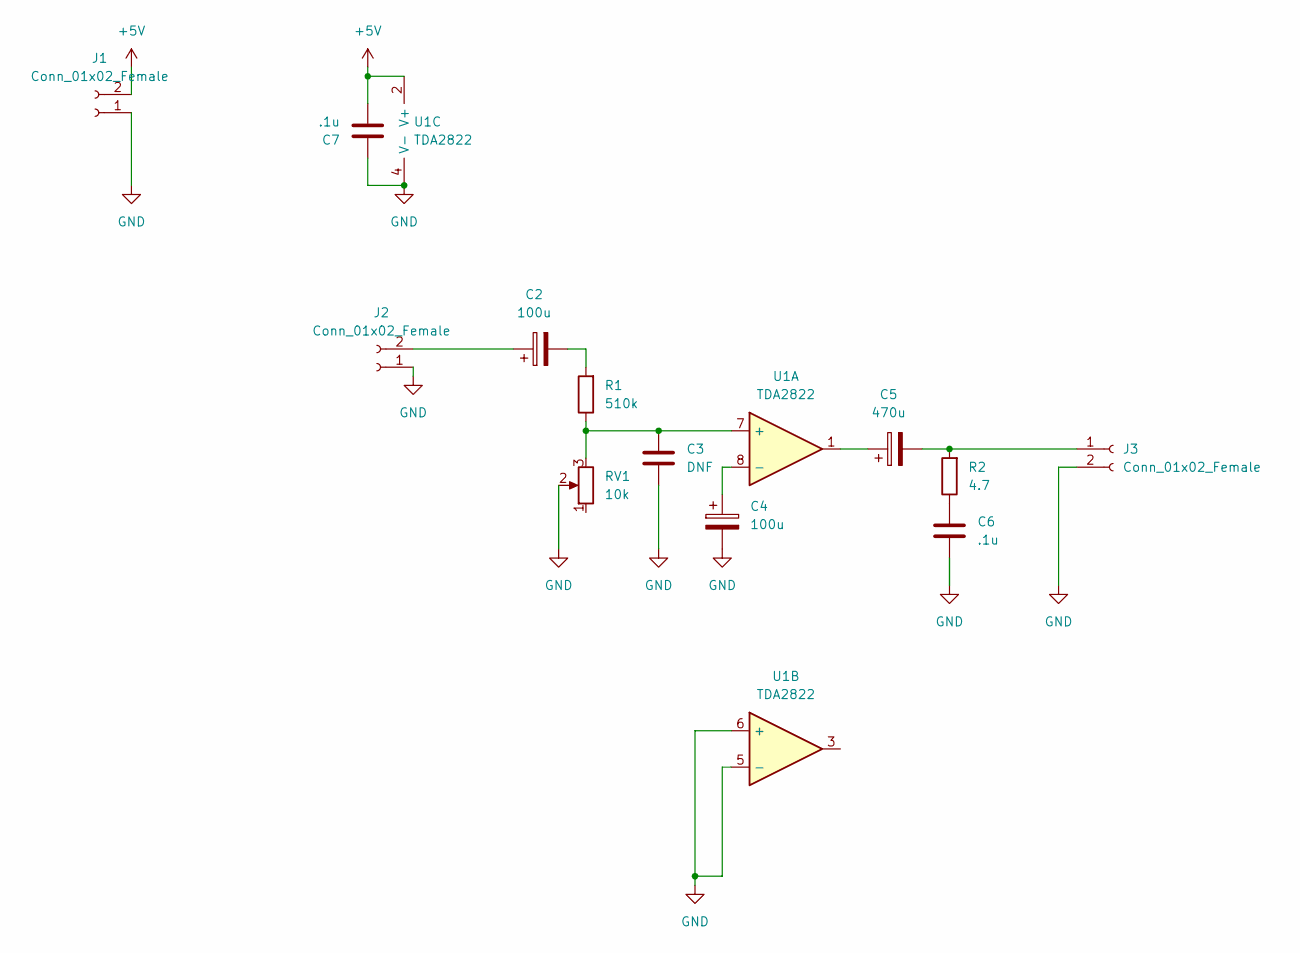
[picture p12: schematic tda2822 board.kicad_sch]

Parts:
C2, C4: 100u; CP_Radial_D5.0mm_P2.50mm
C3: DNF; C_Rect_L4.0mm_W2.5mm_P2.50mm
C5: 470u; CP_Radial_D5.0mm_P2.50mm
C6, C7: .1u; C_Rect_L4.0mm_W2.5mm_P2.50mm
J1, J2, J3: Conn_01x02_Female; PinHeader_1x02_P2.54mm_Vertical
R1: 510k; R_Axial_DIN0207_L6.3mm_D2.5mm_P10.16mm_Horizontal
R2: 4.7; R_Axial_DIN0207_L6.3mm_D2.5mm_P10.16mm_Horizontal
RV1: 10k; PinHeader_1x03_P2.54mm_Vertical
U1: TDA2822; DIP-8_W7.62mm

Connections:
+5V: C7.1, J1.2, U1.2 (V+)
GND: C3.1, C4.2, C6.1, C7.2, J1.1, J2.1, J3.2, RV1.2, U1.4 (V-), U1.5 (-), U1.6 (+)
unnamed: C2.1, J2.2
unnamed: C2.2, R1.2
unnamed: C3.2, R1.1, RV1.3, U1.7 (+)
unnamed: C4.1, U1.8 (-)
unnamed: C5.1, U1.1
unnamed: C5.2, J3.1, R2.2
unnamed: C6.2, R2.1

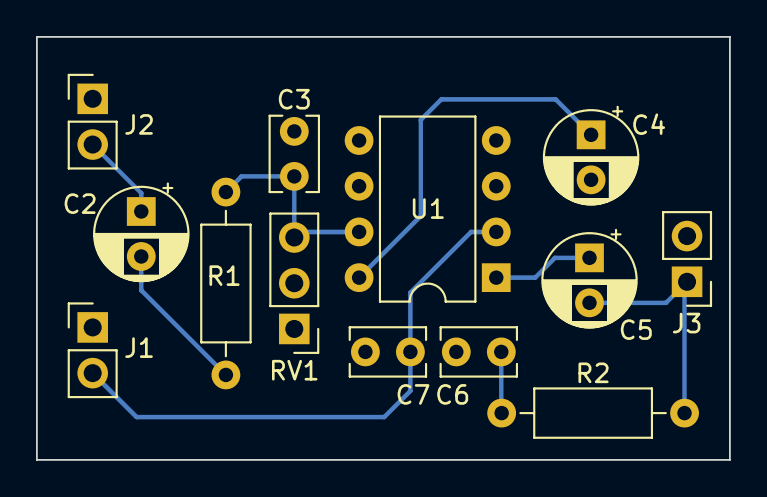
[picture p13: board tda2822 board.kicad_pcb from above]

Board: 2 copper layers, 38.5 x 23.5 mm, 13 parts (0 on the bottom side), 9 nets.

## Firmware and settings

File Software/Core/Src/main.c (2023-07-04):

/*
  Copyright 2023 David Miall
  
  Redistribution and use in source and binary forms, with or without modification, are permitted provided that the following conditions are met:

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
THIS SOFTWARE IS PROVIDED BY THE COPYRIGHT HOLDERS AND CONTRIBUTORS "AS IS" AND ANY EXPRESS OR IMPLIED WARRANTIES, INCLUDING, BUT NOT LIMITED TO, THE IMPLIED WARRANTIES OF MERCHANTABILITY AND FITNESS FOR A PARTICULAR PURPOSE ARE DISCLAIMED. IN NO EVENT SHALL THE COPYRIGHT HOLDER OR CONTRIBUTORS BE LIABLE FOR ANY DIRECT, INDIRECT, INCIDENTAL, SPECIAL, EXEMPLARY, OR CONSEQUENTIAL DAMAGES (INCLUDING, BUT NOT LIMITED TO, PROCUREMENT OF SUBSTITUTE GOODS OR SERVICES; LOSS OF USE, DATA, OR PROFITS; OR BUSINESS INTERRUPTION) HOWEVER CAUSED AND ON ANY THEORY OF LIABILITY, WHETHER IN CONTRACT, STRICT LIABILITY, OR TORT (INCLUDING NEGLIGENCE OR OTHERWISE) ARISING IN ANY WAY OUT OF THE USE OF THIS SOFTWARE, EVEN IF ADVISED OF THE POSSIBILITY OF SUCH DAMAGE.
*/

#include "main.h"
#include "stm32g051xx.h"

#if defined(STM32L152xE)
#include "stm32l152xe.h"
#include "stm32l1xx_it.h"
#elif defined(STM32G051xx)
#include "stm32g0xx.h"
#include "stm32g0xx_it.h"
#endif

#include "sys-setup.h"
#include "waveform.h"
#include <math.h>
#include <stdint.h>

#define VOL_SCALE_MIN 150


volatile uint32_t SYSTICK_VAL = 0;
static volatile DAC_TypeDef *dac = DAC;
static volatile DMA_Channel_TypeDef *dacDma  = DMA1_Channel1;
static volatile DMAMUX_Channel_TypeDef *dacDmaMux = DMAMUX1_Channel0;

static volatile DMA_TypeDef *dma = DMA1;

static volatile TIM_TypeDef *tim1 = TIM1;
static volatile TIM_TypeDef *tim3 = TIM3;
static volatile TIM_TypeDef *tim15 = TIM15;

volatile uint16_t volumeInputBuffer[VOL_CNT_SAMPLES];
volatile uint16_t pitchInputBuffer[FRQ_CNT_SAMPLES];

volatile uint16_t WF_BUFF_1[SAMPLES_NUMBER];
volatile uint16_t WF_BUFF_2[SAMPLES_NUMBER];

volatile uint16_t *ACTIVE_WF_BUF;
volatile uint16_t *INACTIVE_WF_BUF;
volatile uint16_t const *ACTIVE_WF_SRC;
volatile uint8_t WF_PROC_DONE;

volatile uint16_t volumeInputMean;
volatile int32_t volumeScale;
volatile int32_t pitchScale;
volatile uint16_t pitchInputMean;

volatile uint16_t volumeCal;
volatile uint16_t pitchCal;



/**
  * @brief  The application entry point.
  * @retval int
  */
int main(void)
{
  int16_t lastPitchOs = 0;
  volatile int16_t pitchOS = 0;
  int8_t pitchOsSign;
  WF_PROC_DONE = 0;
  ACTIVE_WF_SRC = SINE_WF;
  ACTIVE_WF_BUF = (uint16_t*)WF_BUFF_1;
  INACTIVE_WF_BUF = (uint16_t*)WF_BUFF_2;
  platform_init();
  start_output();

  for (uint32_t i = 0; i<3*UINT16_MAX; i++) {

  }
  volumeCal = volumeInputMean;
  pitchCal = pitchInputMean;
  
  while (1) {
    if (!WF_PROC_DONE){
      //Calculate scaled number by multiplying
      volumeScale = (volumeInputMean - volumeCal);
      if (volumeScale < 10) {
	volumeScale = 10;
      }
      volumeScale += 100;
      //Try leaving pitch-scaling as-is?
      pitchOS = pitchInputMean - pitchCal;

      //pitchScale = (int32_t)((double)(2*log((double)pitchOS)));
      double y = ((double)pitchOS * 3 *exp(-0.0003*(double)pitchOS));
      double y_b = (15*exp(-0.006*(double)pitchOS));
      pitchScale = 2*(y + y_b);
      if (pitchScale < 0) pitchScale = 0;
      //pitchScale = pitchOS*2;
      //pitchScale *= pitchOsSign;
      
      for (uint32_t i = 0; i<SAMPLES_NUMBER; i++) {
	int32_t noDC = (ACTIVE_WF_SRC[i] - MIDPOINT);
	int32_t noDcScaled = (noDC*1000) / (volumeScale*10);
	if (volumeScale > 1000) {
	  noDcScaled = 0;
	}
	noDcScaled += MIDPOINT;
	if (noDcScaled > 4095) {
	  noDcScaled = 4095;
	}

	INACTIVE_WF_BUF[i] =  (uint16_t)noDcScaled;
      }
      WF_PROC_DONE = 1;
      }
    //volumeScale = 3;
  }
}

//Pitch/Volume transfer done
void DMA1_Channel2_3_IRQHandler () {
  uint32_t count = 0;
  if (DMA1->ISR & 1U << DMA_ISR_TCIF2_Pos) { //Pitch transfer done
    DMA1->IFCR |= (1U << DMA_IFCR_CTCIF2_Pos) | (1U << DMA_IFCR_CGIF2_Pos);
    for (uint16_t i = 0; i<FRQ_CNT_SAMPLES; i++) {
      count += pitchInputBuffer[i];
    }
    pitchInputMean = count/FRQ_CNT_SAMPLES; //Divide by 32
  }
}

void DMA1_Ch4_7_DMAMUX1_OVR_IRQHandler() {
  uint32_t count = 0;
  if (DMA1->ISR & 1U << DMA_ISR_TCIF4_Pos) { //Volume transfer done
    DMA1->IFCR |= (1U << DMA_IFCR_CTCIF4_Pos) | (1U << DMA_IFCR_CGIF4_Pos);
    for (uint8_t i = 0; i<VOL_CNT_SAMPLES; i++) {
      count += volumeInputBuffer[i];
    }
    volumeInputMean = count/VOL_CNT_SAMPLES; //Divide by 64
  }
}

//Wave transfer done
void DMA1_Channel1_IRQHandler () {
  if (DMA1->ISR & 1U << DMA_ISR_TCIF1_Pos) {
    DMA1->IFCR |= 1U << DMA_IFCR_CTCIF1_Pos;
    if (WF_PROC_DONE) {
      DMA1_Channel3->CMAR = (uint32_t)((uint16_t*)INACTIVE_WF_BUF);
      uint16_t* tempWfBuf = (uint16_t*)ACTIVE_WF_BUF;
      ACTIVE_WF_BUF = INACTIVE_WF_BUF;
      INACTIVE_WF_BUF = tempWfBuf;
      offsetDacTimer(-pitchScale); //Apply in TCIRQ for synch
      WF_PROC_DONE = 0;
      }
  }
}


/**
  * @brief This function handles System tick timer.
  */
void SysTick_Handler(void)
{
  SYSTICK_VAL ++;
}

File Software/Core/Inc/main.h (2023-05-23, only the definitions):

#define B1_Pin GPIO_PIN_13
#define B1_GPIO_Port GPIOC
#define USART_TX_Pin GPIO_PIN_2
#define USART_TX_GPIO_Port GPIOA
#define USART_RX_Pin GPIO_PIN_3
#define USART_RX_GPIO_Port GPIOA
#define LD2_Pin GPIO_PIN_5
#define LD2_GPIO_Port GPIOA
#define TMS_Pin GPIO_PIN_13
#define TMS_GPIO_Port GPIOA
#define TCK_Pin GPIO_PIN_14
#define TCK_GPIO_Port GPIOA
#define SWO_Pin GPIO_PIN_3
#define SWO_GPIO_Port GPIOB

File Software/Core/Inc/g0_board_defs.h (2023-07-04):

#ifndef g0DEFS_h
#define g0DEFS_h

#define DAC_OUT_PIN 4
#define PITCH_PIN 6
#define VOLUME_PIN 2
#define CAL_PIN 7

#endif

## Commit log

2023-05-23 DAC Output a Sine Wave. Re-add Bridge amp
    [Digital Theremin.kicad_sch]
2023-05-24 Software. Add filter cap
    [Digital Theremin.kicad_pcb, Digital Theremin.kicad_sch]
2023-05-25 Measure frequency from timers
2023-05-26 Working pitch. Revert to Single Ended amplifier
    [Digital Theremin.kicad_sch]
2023-05-26 Volume and pitch
2023-05-27 Single ended layout
    [Digital Theremin.kicad_pcb, Digital Theremin.kicad_sch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]
2023-05-28 Antenna mounts
    [Digital Theremin.kicad_pcb, Digital Theremin.kicad_sch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]
2023-05-29 Flip amp board
    [tda2822 board.kicad_pcb]
2023-07-04 Working Software for board
2023-07-04 Set DNF
    [Digital Theremin.csv, Digital Theremin.kicad_pcb, Digital Theremin.kicad_sch]
2023-07-04 adjust pitch scaling
2023-07-13 Add how-to
    [Digital Theremin.kicad_pcb, Digital Theremin.kicad_sch, digital.kicad_sch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]

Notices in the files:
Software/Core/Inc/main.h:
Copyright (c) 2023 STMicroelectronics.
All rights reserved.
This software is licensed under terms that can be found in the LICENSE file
